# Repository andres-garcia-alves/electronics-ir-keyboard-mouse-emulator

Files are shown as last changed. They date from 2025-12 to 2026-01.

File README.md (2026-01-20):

# IR Keyboard+Mouse Emulator

Electronic project for use a IR Remote Control to control a Home Theater PC (HTPC) based on Arduino PRO Micro.  
Schematics diagram + PCB diagram (KiCAD 9) and case 3D model (Blender) are also provided.

This project comes in two versions: `Allways On` and `Low Power`.  
**Very important**: the current status of the `Low Power` version is **not working**, maybe I'll give it another try in the future.

- The `Allways On` version provides an immediate response when a remote control button is pressed.  
However, the gadget will constantly draw approximately 35-40mA from the USB port.

- The `Low Power` version automatically powers down the device after 30 seconds of inactivity, and it powers back on upon receiving an IR signal.  
This allows the gadget's power consumption to drop 99% of the time to ~1mA (the consumption of the IR sensor, the only component that remains powered on).  
However, due to the power-up time and the wait for the PC to recognize the device, there is a slight delay before it can be used.  
A high-side topology is used to power down the Arduino.
  - Hardware Variant A: External connection with a USB-A cable to J1 (USB-A socket).  
    Use a 2-strand cable from J2 (2-pins header) to the USB jack of Arduino for **data only** (D+/D-).
  - Hardware Variant B: External connection with a USB-B mini/micro cable to Arduino.  
    Cut the VCC wire of USB-B cable and pass it through J1 (2-pins header).

&nbsp;

General commands:
- Key Lock/Unlock (to avoid collition with regular TV usage).
- Key Esc
- Key Close (close current program)
- Mouse Change Speed
- Mouse Left Click
- Mouse Right Click
- Mouse MoveUp
- Mouse Move Right
- Mouse MoveDown
- Mouse MoveLeft

Media commands
- Media Player (open VLC media player)
- Media Play/Pause
- Media Stop
- Media Forward (moves forward 10 seconds)
- Media Rewind (moves backwards 10 seconds)
- Media Previous (moves forward 1 minute)
- Media Next (moves backwards 1 minute)
- Media Volume Mute
- Media Volume Up
- Media Volume Down

Miscellaneous commands
- MyPC (opens MyPC)
- Calculator (open Calculator);

Features:
- Dump of IR Codes (protocols: RC5, RC6, NEC, SONY, PANASONIC, LG, JVC, WHYNTER)

Benchmarks:

| Arduino PRO Micro | Tipical consumption |
|---|---|
| Normal mode | 37-38 mA |
| ADC + SPI + TWI disabled | 35-36 mA |
| USB detach + Clock @2 MHz | 19-20 mA |
| USB detach + SLEEP_MODE_PWR_DOWN  | 4-5 mA |

I am currently working on incorporating a hardware low-power version.

&nbsp;

The `Allways ON` version uses the following electronic components:
- 1 x Arduino PRO Micro
- 1 x IR Receiver VS1838
- 1 x LED 3mm
- 1 x 1k ohm resistor

The `Low Power` version uses the following electronic components:
- 1 x Arduino PRO Micro
- 1 x IR Receiver VS1838
- 1 x LED 3mm
- 1 x 1k ohm resistor
- 1 x 47k ohm resistor
- 2 x 10k ohm resistor
- 1 x 100k ohm resistor
- 2 x 4.7k ohm resistor
- 3 x 1N4148 schottky diode
- 1 x 10uF electrolitic capacitor
- 3 x BC547 PNP transistor
- 2 x BC557 NPN transistor
- 1 x USB Type-A female connector
- 1 x Bornier 2-pins / JST connector 2-pins

&nbsp;

### Version Allways On

| Breadboard | Assembly |
|---|---|
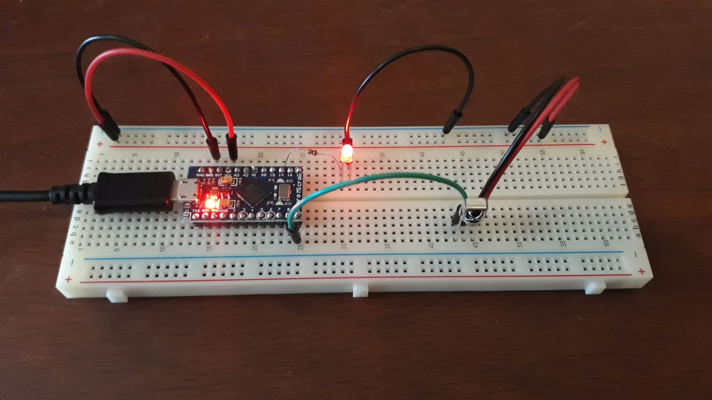
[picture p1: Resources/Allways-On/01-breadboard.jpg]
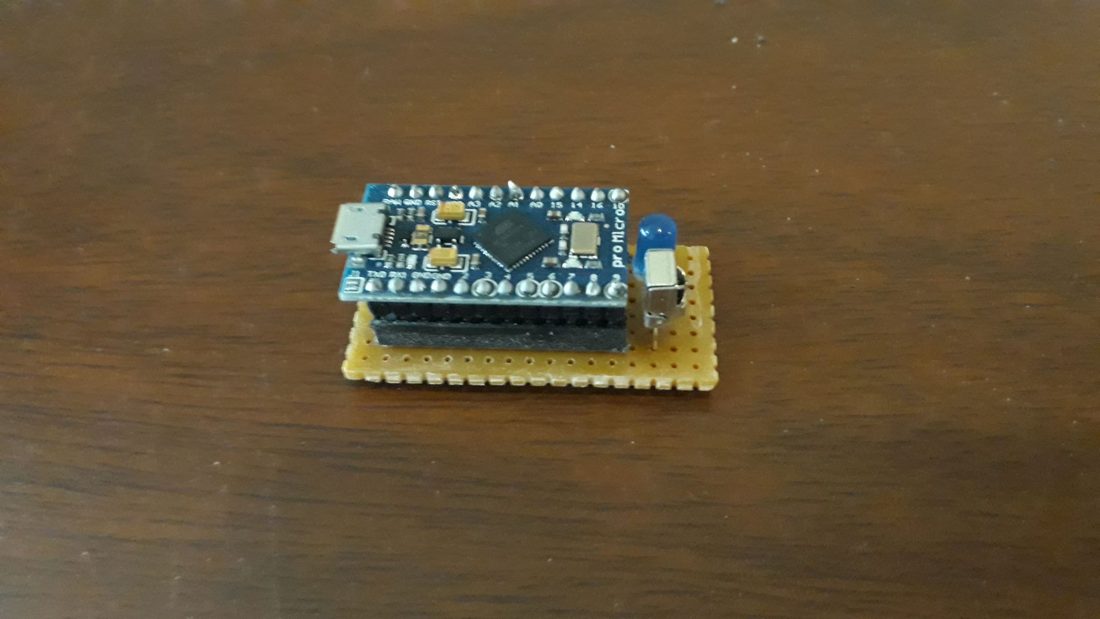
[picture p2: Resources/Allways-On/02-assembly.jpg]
|  |  |

| Schematics Diagram | PCB Diagram |
|---|---|
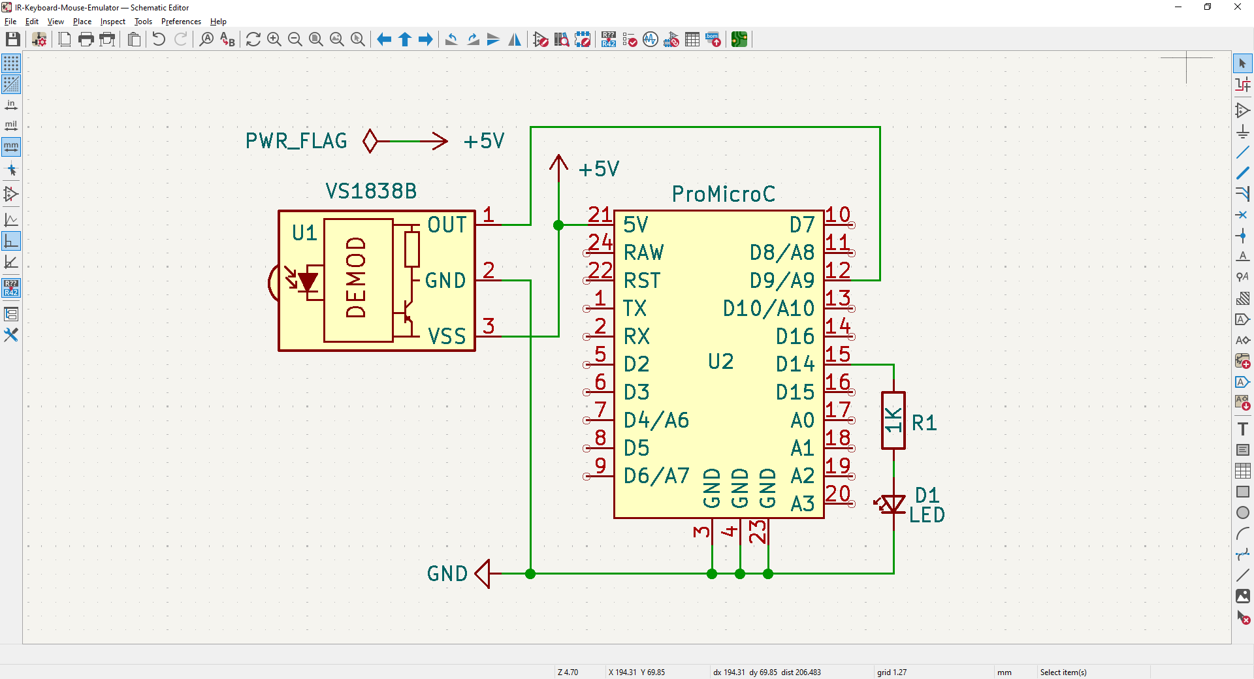
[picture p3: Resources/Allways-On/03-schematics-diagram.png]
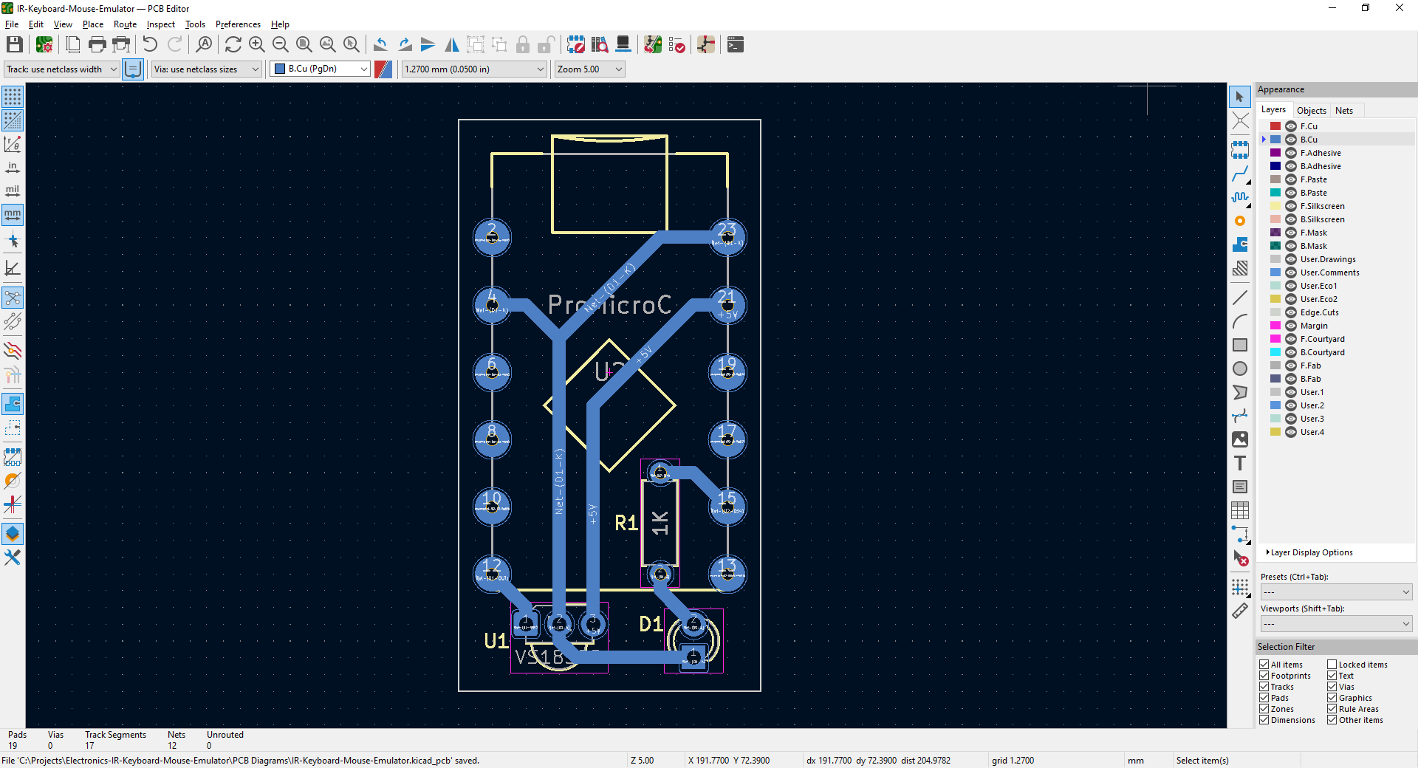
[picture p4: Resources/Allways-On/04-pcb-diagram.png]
|  |  |

| PCB Render 3D | PCB Render 3D |
|---|---|
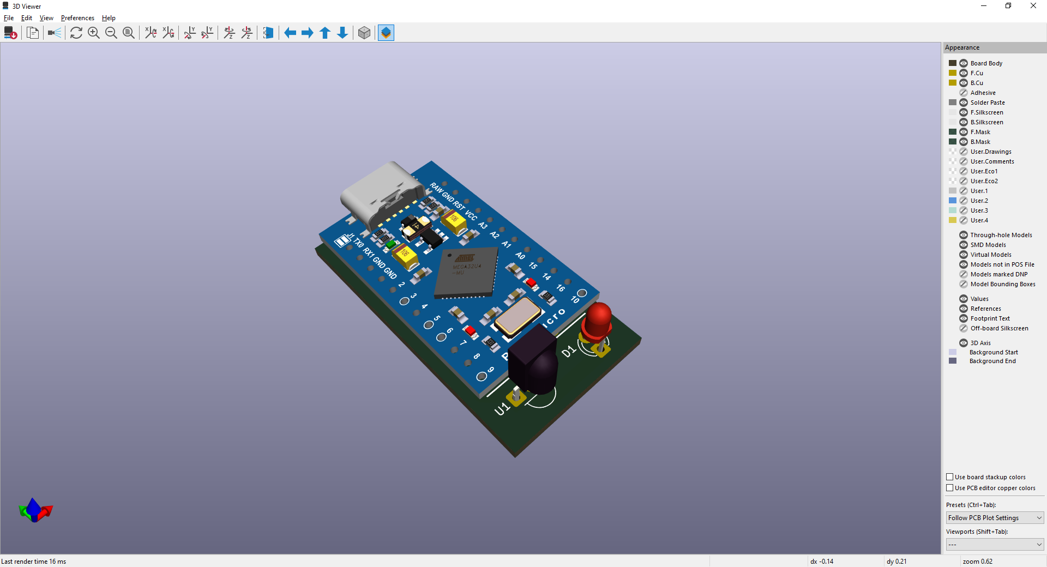
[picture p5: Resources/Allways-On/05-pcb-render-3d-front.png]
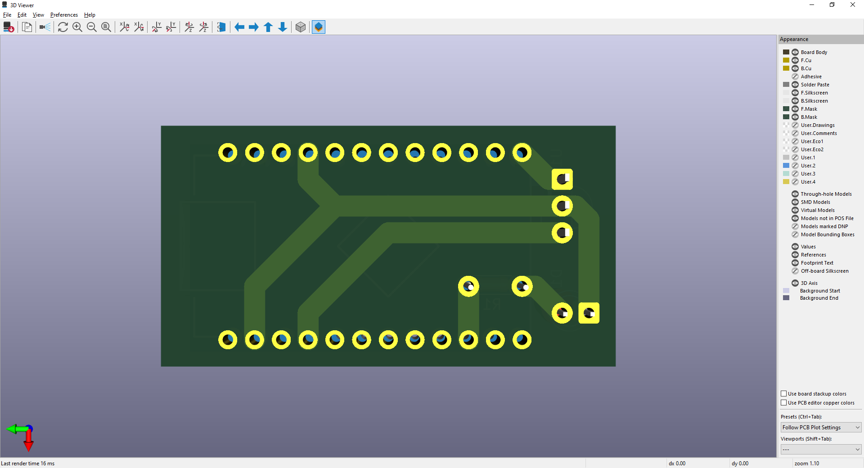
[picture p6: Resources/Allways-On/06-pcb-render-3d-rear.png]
|   |  |

| Case 3D Model | Project Final |
|---|---|
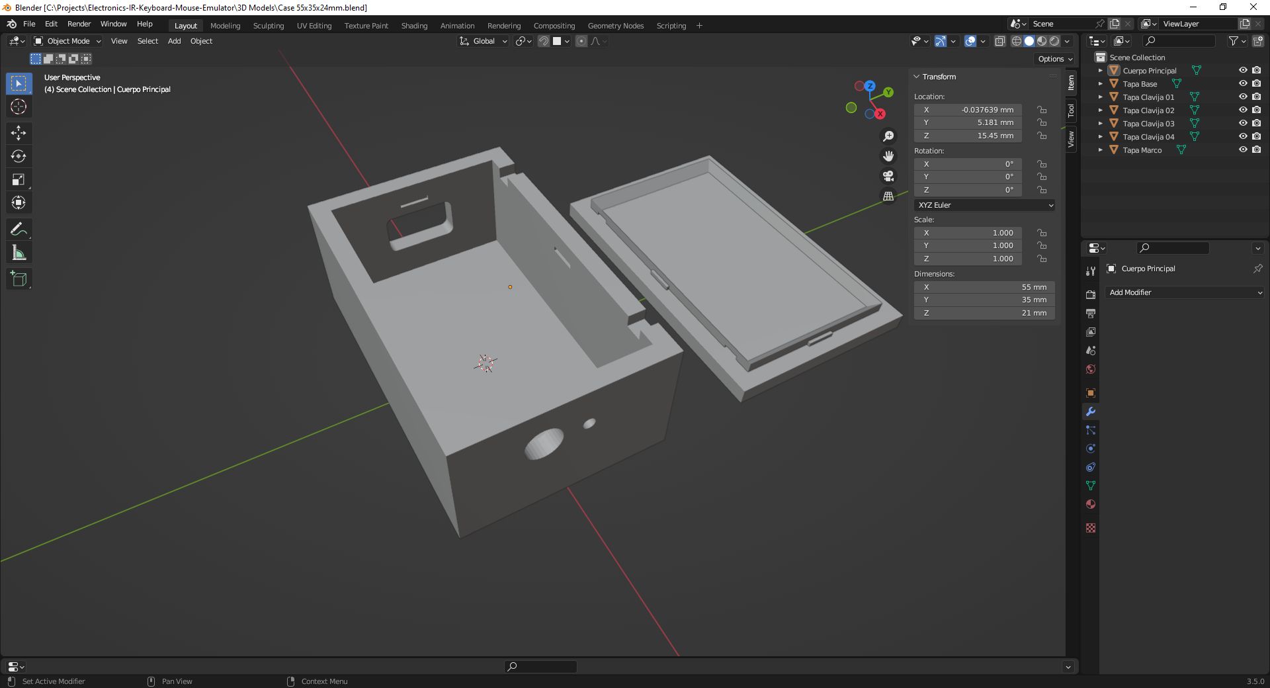
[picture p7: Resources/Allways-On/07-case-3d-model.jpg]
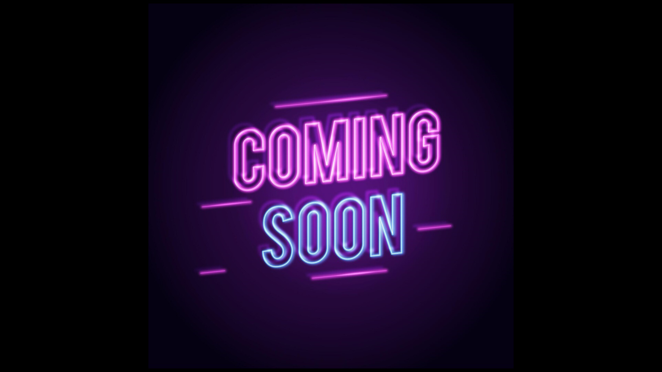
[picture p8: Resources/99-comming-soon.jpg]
|  |  |

&nbsp;

### Version Low-Power-B

| Breadboard | Assembly |
|---|---|
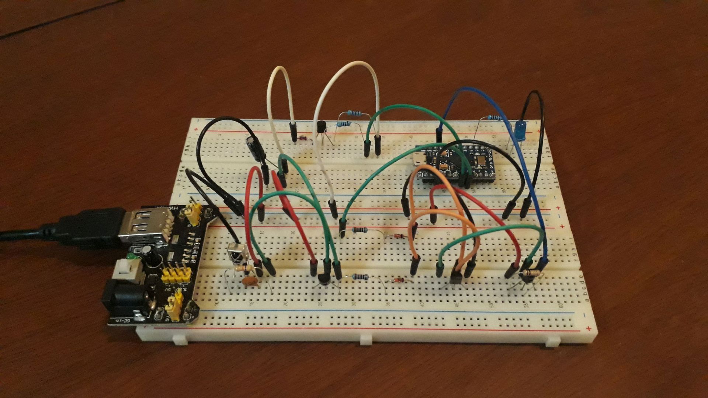
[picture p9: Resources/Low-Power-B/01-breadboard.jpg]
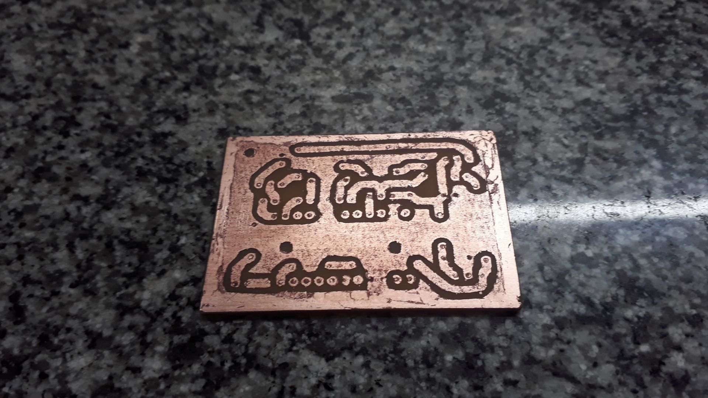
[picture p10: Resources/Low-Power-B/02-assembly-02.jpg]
|  |  |

| Assembly | Assembly |
|---|---|
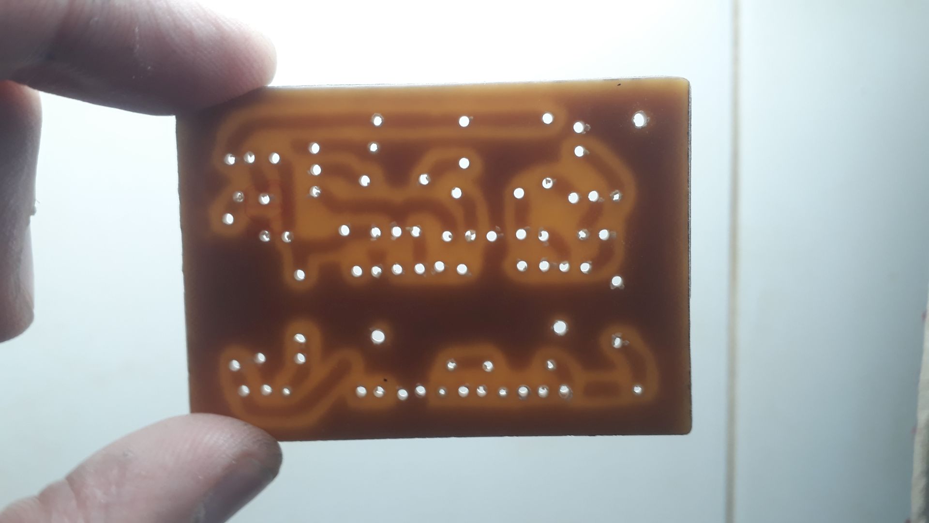
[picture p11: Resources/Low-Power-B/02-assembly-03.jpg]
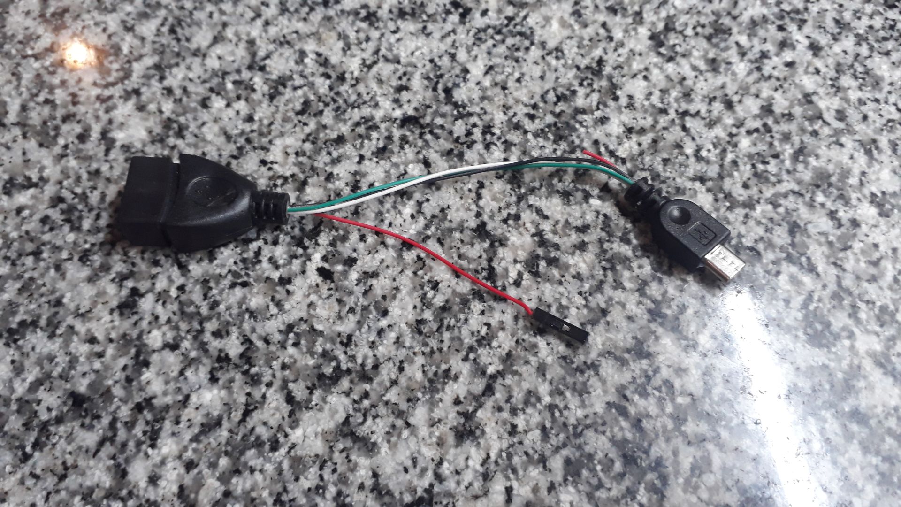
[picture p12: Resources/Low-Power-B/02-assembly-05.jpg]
|  |  |

| Schematics Diagram | PCB Diagram |
|---|---|
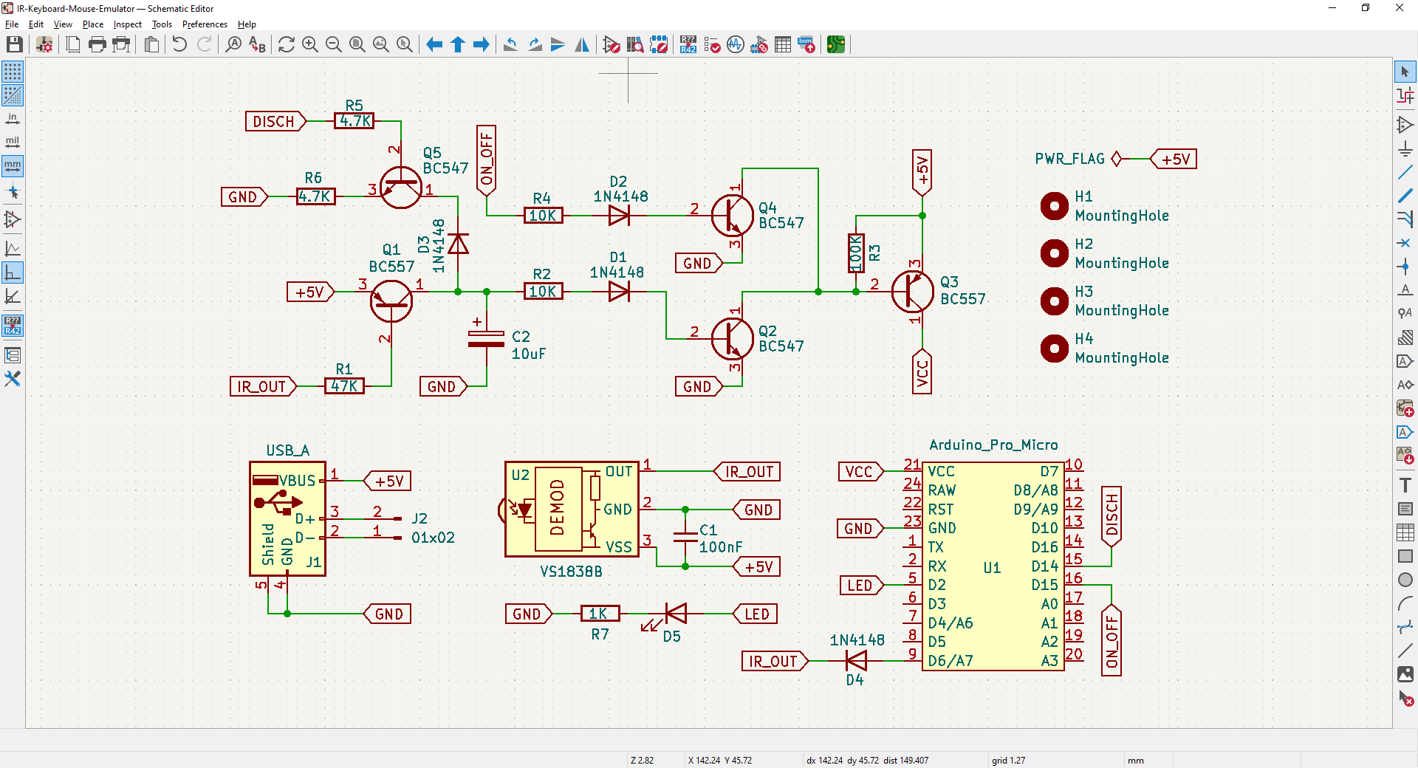
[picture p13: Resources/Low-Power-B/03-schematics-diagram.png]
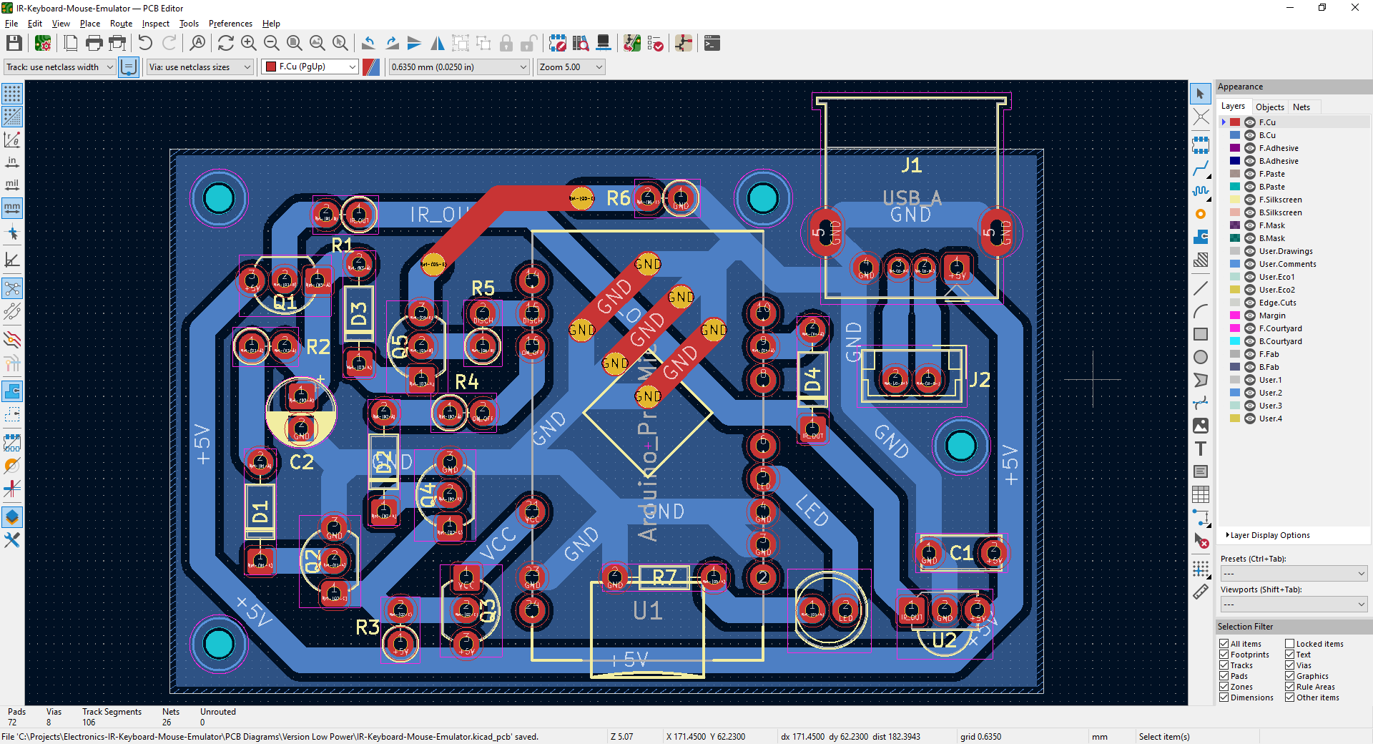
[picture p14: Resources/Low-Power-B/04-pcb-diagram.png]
|   |  |

| PCB Render 3D | PCB Render 3D |
|---|---|
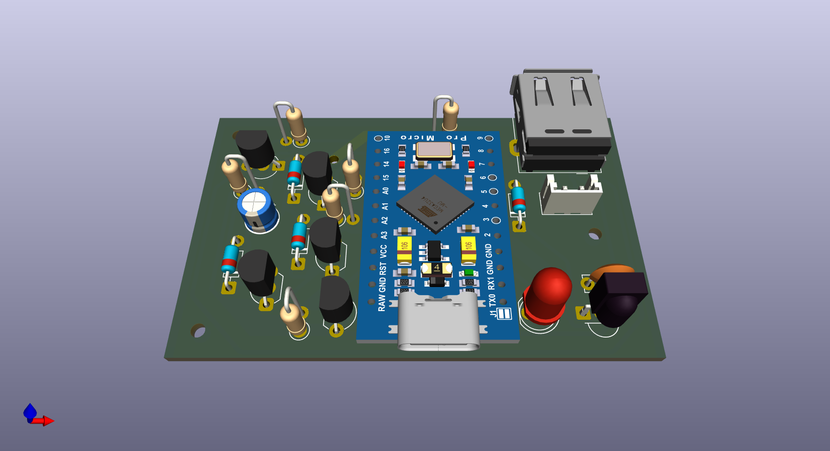
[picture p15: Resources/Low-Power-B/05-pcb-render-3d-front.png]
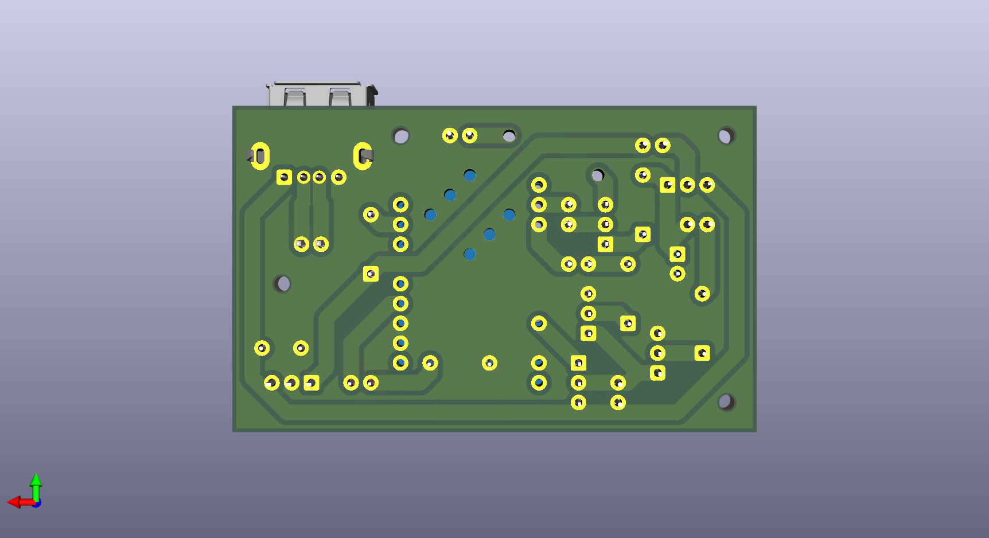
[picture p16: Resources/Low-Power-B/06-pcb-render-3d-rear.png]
|  |   |

| Case 3D Model | Project Final |
|---|---|
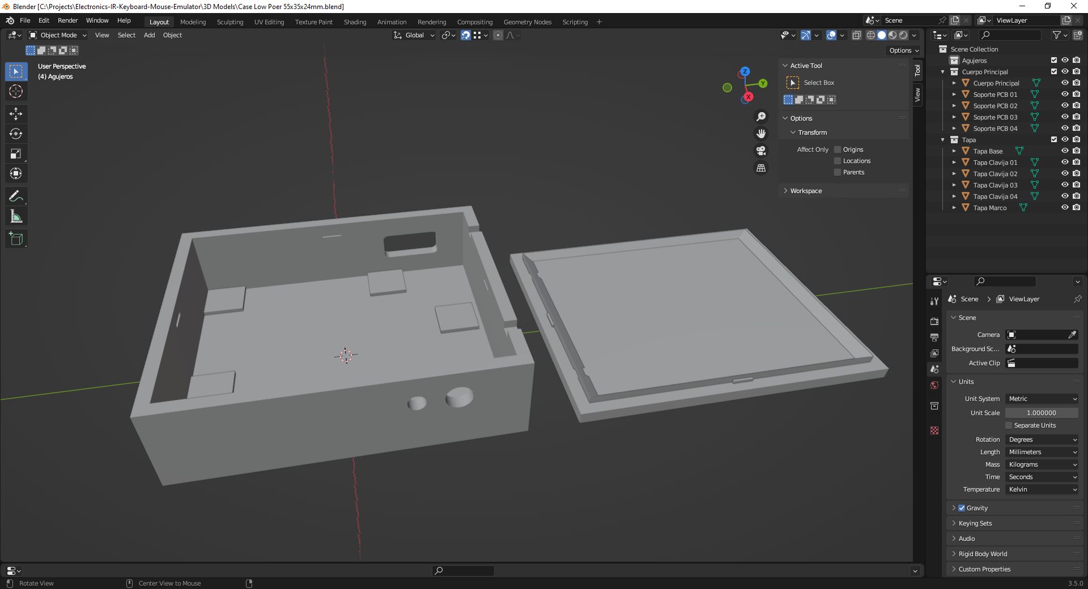
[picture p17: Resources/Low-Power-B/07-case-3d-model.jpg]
|  |  |

See 'Rescources' sub-folder for more pictures & videos of the project.

&nbsp;

### Version History

v1.00 (2025.12.18) - Initial release.  
v1.01 (2025.12.19) - Adding case 3D model.  
v1.02 (2025.12.22) - Update schematics and PCB.  
v1.03 (2025.12.29) - Firmware refactor for code clean-up.  
v1.04 (2026.01.02) - Adding Low-Power-A version protoboard & schematics.  
v1.05 (2026.01.03) - Adding Low-Power-A version firmware.  
v1.06 (2026.01.04) - Adding Low-Power-A version PCB.  
v1.07 (2026.01.04) - Adding Low-Power-A case 3D model.  
v1.08 (2026.01.06) - Minor fixes on Low-Power-A case 3D model.  
v1.09 (2026.01.09) - Minor fixes on Low-Power-A PCB.  
v1.10 (2026.01.14) - Adding Low-Power-B version schematics & PCB.  
v1.11 (2026.01.15) - Adding Low-Power-B 3D model.  
v1.12 (2026.01.18) - Minor fixes on Low-Power-B 3D model.  

&nbsp;

This source code is licensed under GPL v3.0  
Please send me your feedback about this project: andres.garcia.alves@gmail.com

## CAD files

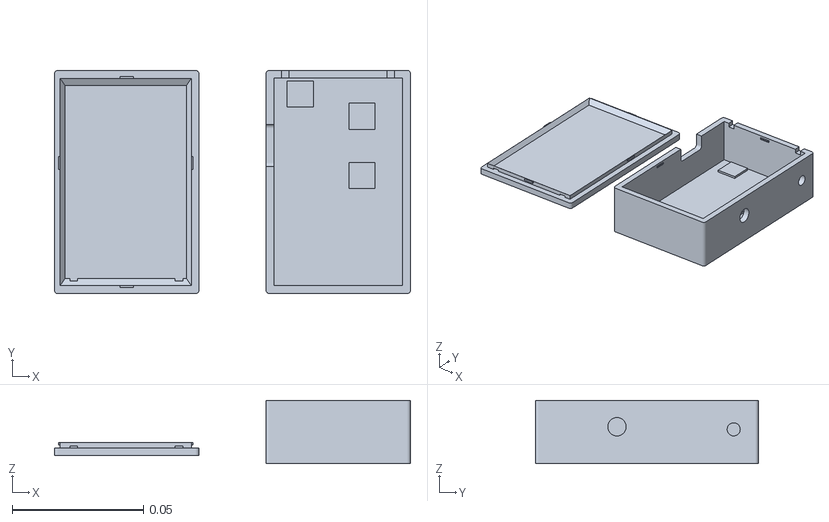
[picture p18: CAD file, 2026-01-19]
3D Models/Case Low-Power-B 85x55x27mm (final).stl
0.136 x 0.085 x 0.024

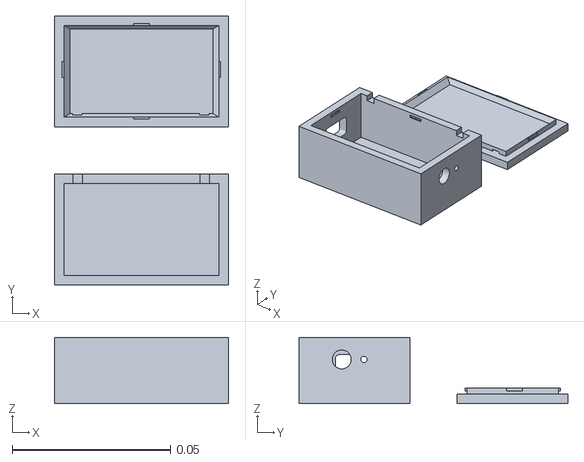
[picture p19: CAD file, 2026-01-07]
3D Models/Case Allways-On 55x35x24mm (final).stl
0.055 x 0.085 x 0.021

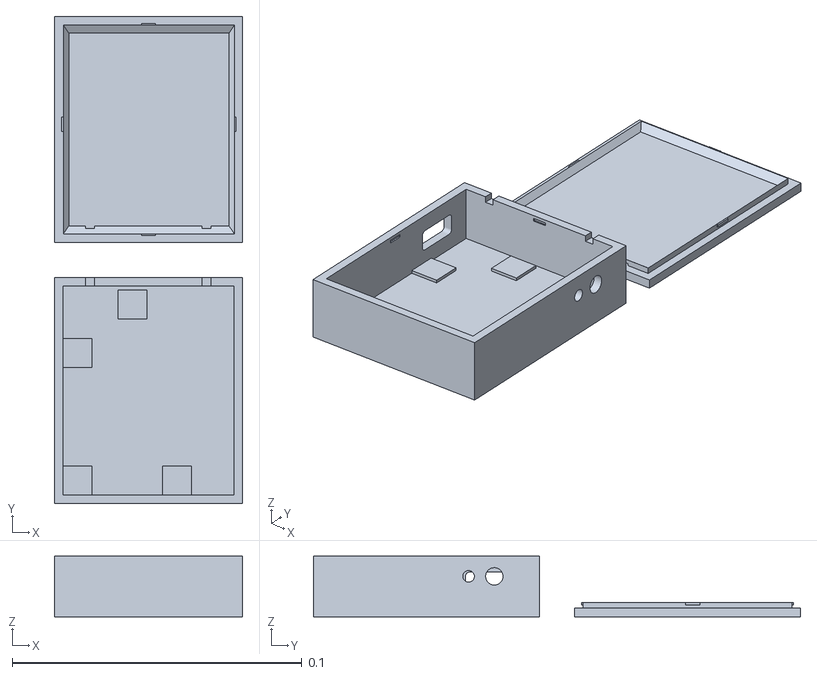
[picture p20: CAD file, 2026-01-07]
3D Models/Case Low-Power-A 65x78x24mm (final).stl
0.065 x 0.168 x 0.021

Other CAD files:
3D Models/Case Allways-On 55x35x24mm (final).blend
3D Models/Case Allways-On 55x35x24mm (without holes).blend
3D Models/Case Low-Power-A 65x78x24mm (final).blend
3D Models/Case Low-Power-A 65x78x24mm (without holes).blend
3D Models/Case Low-Power-B 85x55x27mm (final).blend
3D Models/Case Low-Power-B 85x55x27mm (without holes).blend

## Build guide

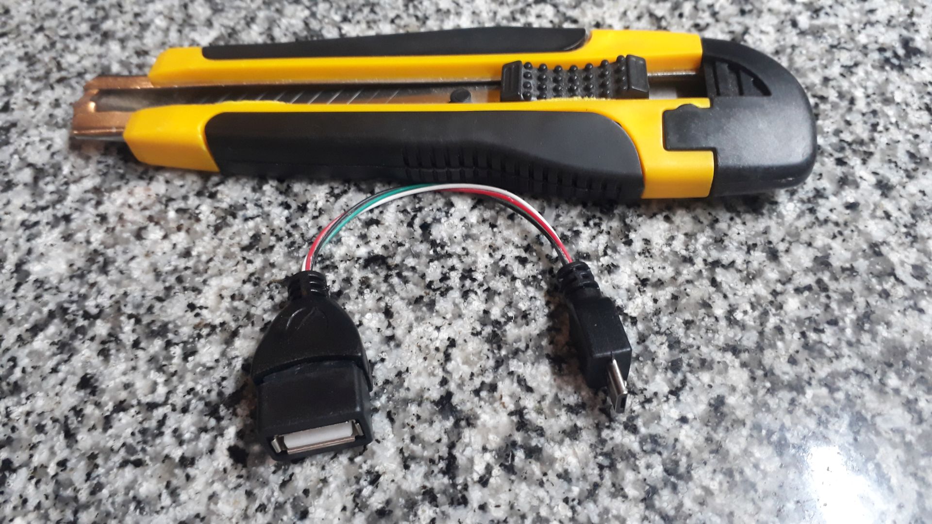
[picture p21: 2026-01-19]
Resources/Low-Power-B/02-assembly-04.jpg

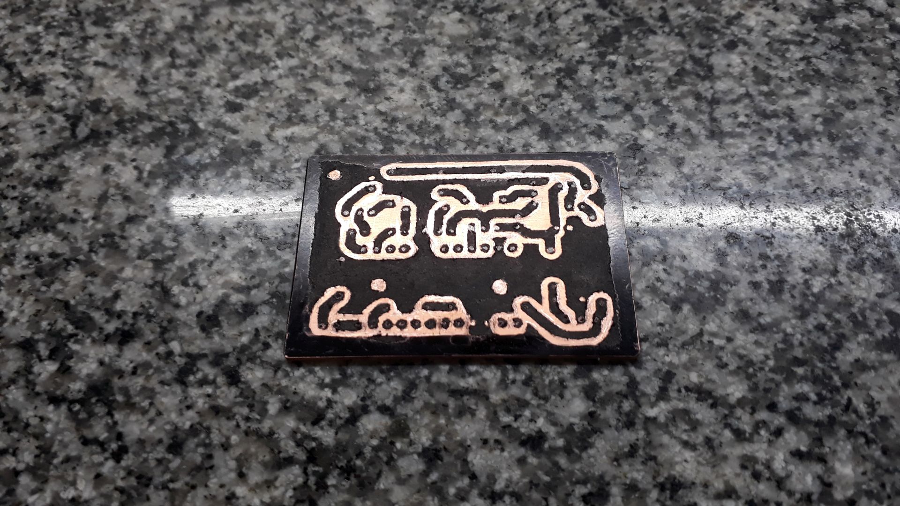
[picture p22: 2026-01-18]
Resources/Low-Power-B/02-assembly-01.jpg

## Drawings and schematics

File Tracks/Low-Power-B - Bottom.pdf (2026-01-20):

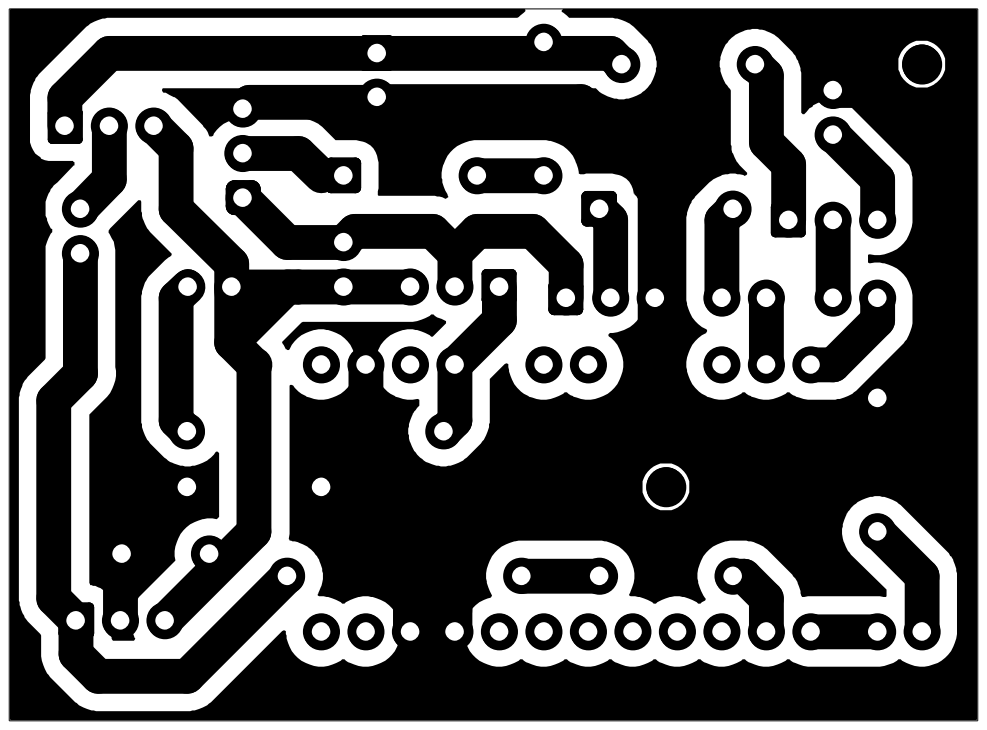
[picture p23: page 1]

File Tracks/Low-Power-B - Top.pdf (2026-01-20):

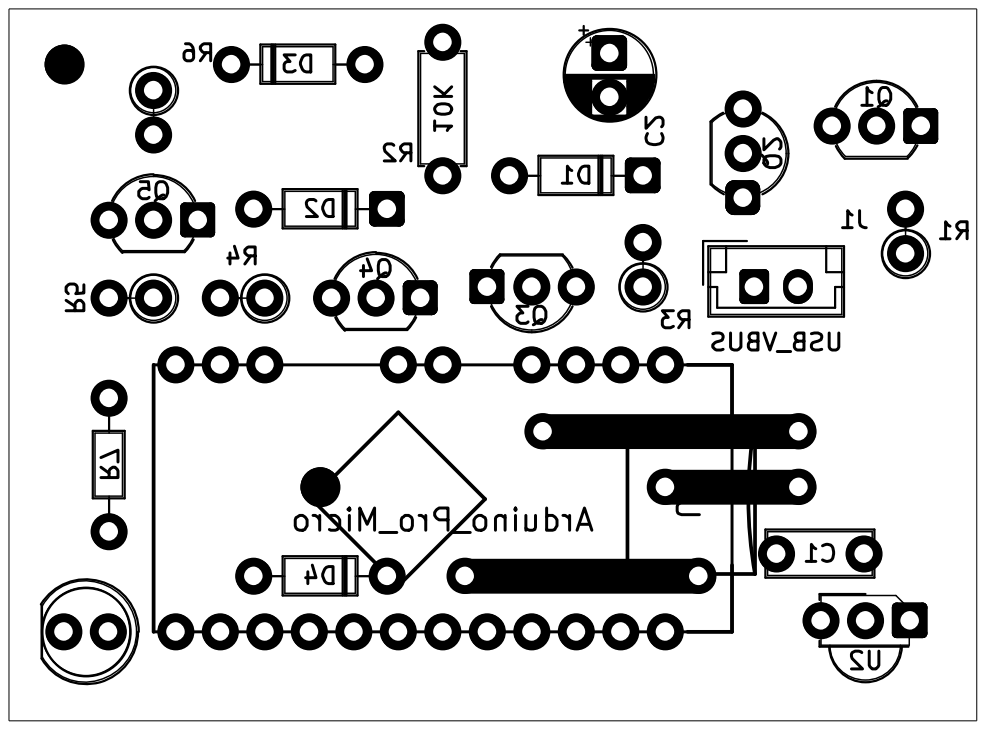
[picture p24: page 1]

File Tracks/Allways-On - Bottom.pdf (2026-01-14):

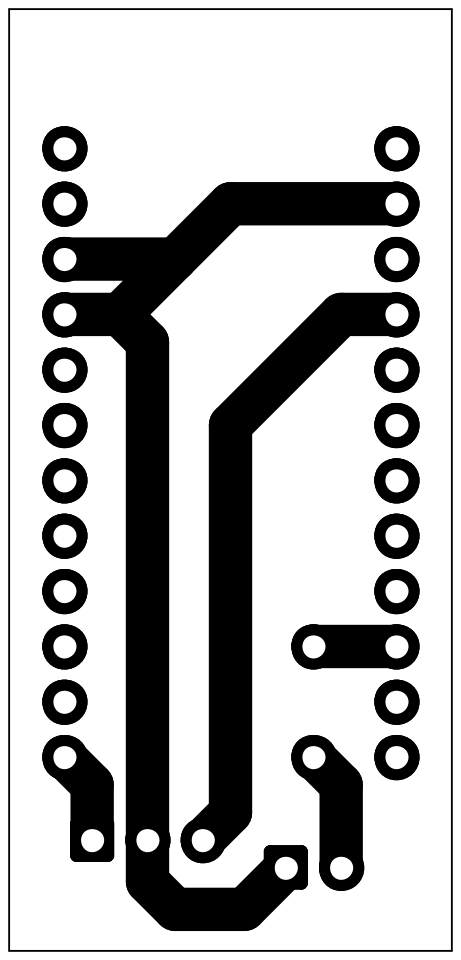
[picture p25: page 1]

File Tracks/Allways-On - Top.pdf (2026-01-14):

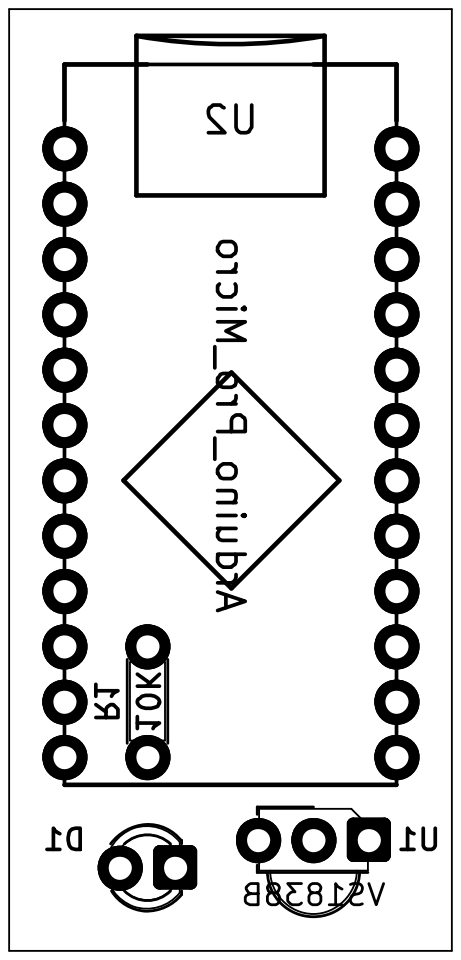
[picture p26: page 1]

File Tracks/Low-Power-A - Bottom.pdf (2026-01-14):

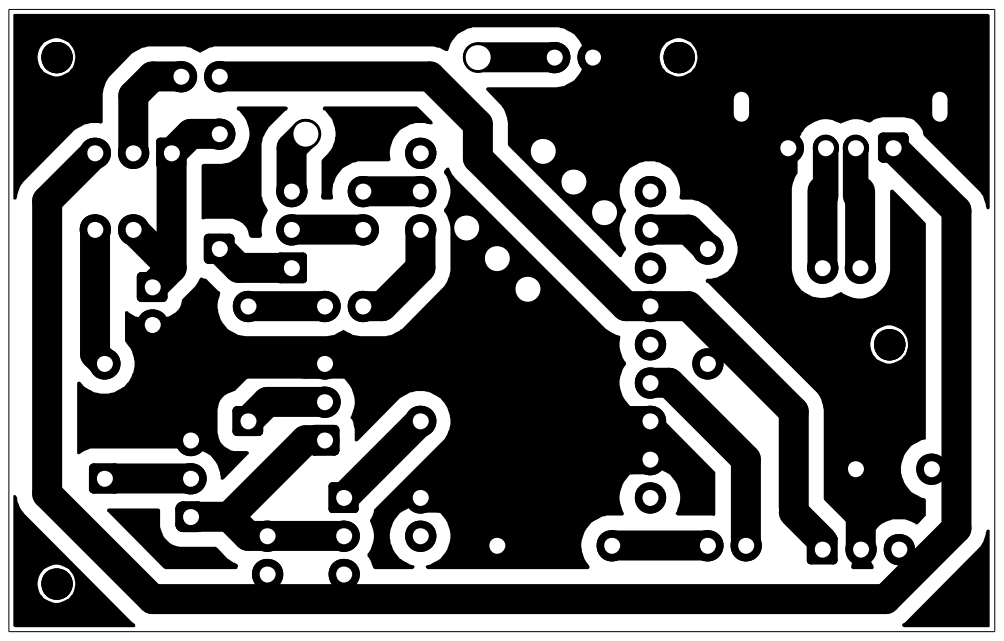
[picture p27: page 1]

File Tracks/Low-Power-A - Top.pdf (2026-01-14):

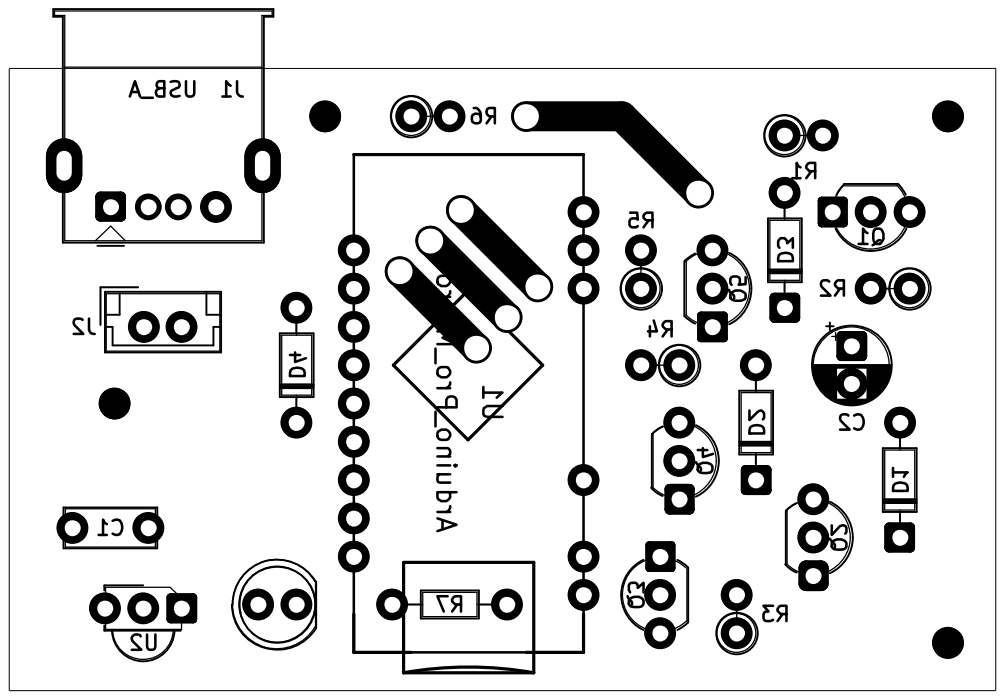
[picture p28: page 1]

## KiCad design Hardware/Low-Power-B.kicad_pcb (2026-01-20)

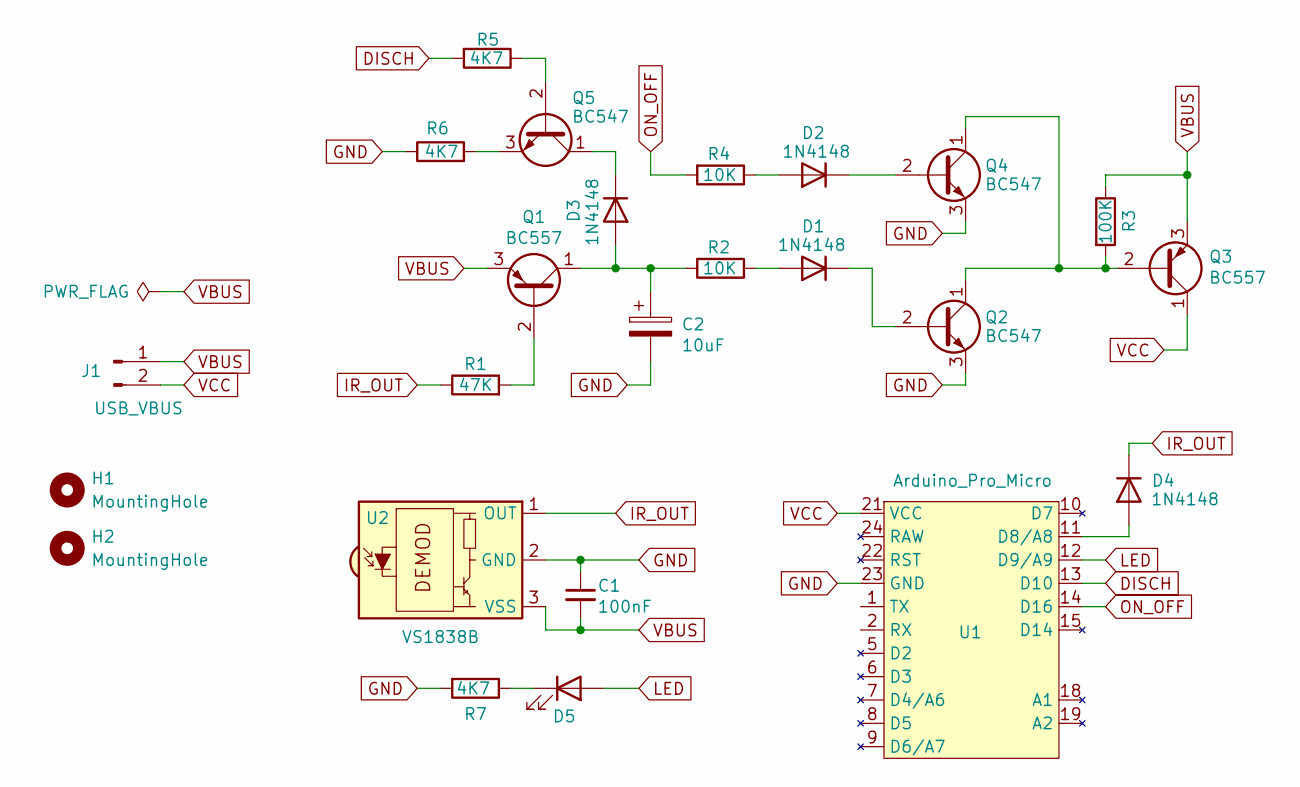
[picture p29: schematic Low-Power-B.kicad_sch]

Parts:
C1: 100nF; C_Disc_D6.0mm_W2.5mm_P5.00mm; Voltage 1kV; Tolerance 100%
C2: 10uF; CP_Radial_D5.0mm_P2.50mm
D1, D2, D3, D4: 1N4148; D_DO-35_SOD27_P7.62mm_Horizontal
D5: LED; LED_D5.0mm
H1, H2: MountingHole; MountingHole_2.2mm_M2_ISO7380
J1: USB_VBUS; JST_EH_B2B-EH-A_1x02_P2.50mm_Vertical
Q1, Q3: BC557; TO-92_Inline_Wide
Q2, Q4, Q5: BC547; TO-92_Inline_Wide
R1: 47K; R_Axial_DIN0207_L6.3mm_D2.5mm_P2.54mm_Vertical
R2: 10K; R_Axial_DIN0207_L6.3mm_D2.5mm_P7.62mm_Horizontal
R3: 100K; R_Axial_DIN0207_L6.3mm_D2.5mm_P2.54mm_Vertical
R4: 10K; R_Axial_DIN0207_L6.3mm_D2.5mm_P2.54mm_Vertical
R5, R6: 4K7; R_Axial_DIN0207_L6.3mm_D2.5mm_P2.54mm_Vertical
R7: 4K7; R_Axial_DIN0204_L3.6mm_D1.6mm_P7.62mm_Horizontal
U1: Arduino_Pro_Micro
U2: VS1838B; Vishay_MINICAST-3Pin

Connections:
DISCH: R5.2, U1.13 (D10)
GND: C1.1, C2.2, Q2.3 (E), Q4.3 (E), R6.1, R7.2, U1.3 (GND), U1.4 (GND), U1.23 (GND), U2.2 (GND)
IR_OUT: D4.1 (K), R1.1, U2.1 (OUT)
LED: D5.2 (A), U1.12 (D9/A9)
unnamed: D1.2 (A), R2.1
unnamed: D1.1 (K), Q2.2 (B)
unnamed: D2.2 (A), R4.1
unnamed: D2.1 (K), Q4.2 (B)
unnamed: C2.1, D3.2 (A), Q1.1 (C), R2.2
unnamed: D3.1 (K), Q5.1 (C)
unnamed: D4.2 (A), U1.11 (D8/A8)
unnamed: D5.1 (K), R7.1
unnamed: Q1.2 (B), R1.2
unnamed: Q2.1 (C), Q3.2 (B), Q4.1 (C), R3.2
unnamed: Q5.2 (B), R5.1
unnamed: Q5.3 (E), R6.2
ON_OFF: R4.2, U1.14 (D16)
VBUS: C1.2, J1.1, Q1.3 (E), Q3.3 (E), R3.1, U2.3 (VSS)
VCC: J1.2, Q3.1 (C), U1.21 (VCC)

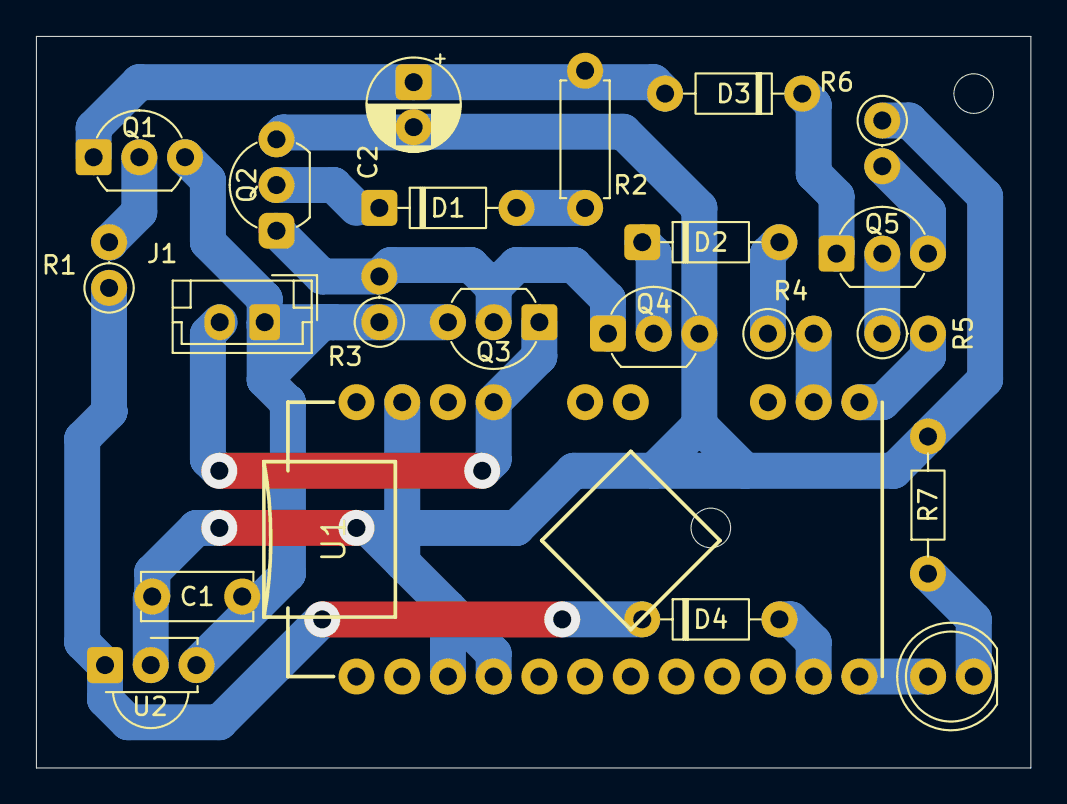
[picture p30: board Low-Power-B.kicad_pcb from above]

Board: 2 copper layers, 55.2 x 40.6 mm, 24 parts (0 on the bottom side), 19 nets.

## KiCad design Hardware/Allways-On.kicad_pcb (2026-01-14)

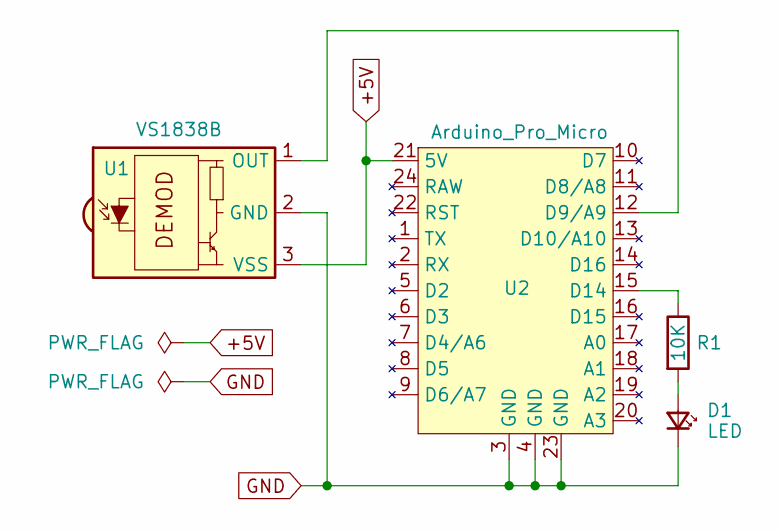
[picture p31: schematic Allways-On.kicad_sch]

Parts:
D1: LED; LED_D3.0mm
R1: 10K; R_Axial_DIN0204_L3.6mm_D1.6mm_P5.08mm_Horizontal
U1: VS1838B; Vishay_MINICAST-3Pin
U2: Arduino_Pro_Micro

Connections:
+5V: U1.3 (VSS), U2.21 (5V)
GND: D1.1 (K), U1.2 (GND), U2.3 (GND), U2.4 (GND), U2.23 (GND)
unnamed: D1.2 (A), R1.2
unnamed: U1.1 (OUT), U2.12 (D9/A9)
unnamed: R1.1, U2.15 (D14)

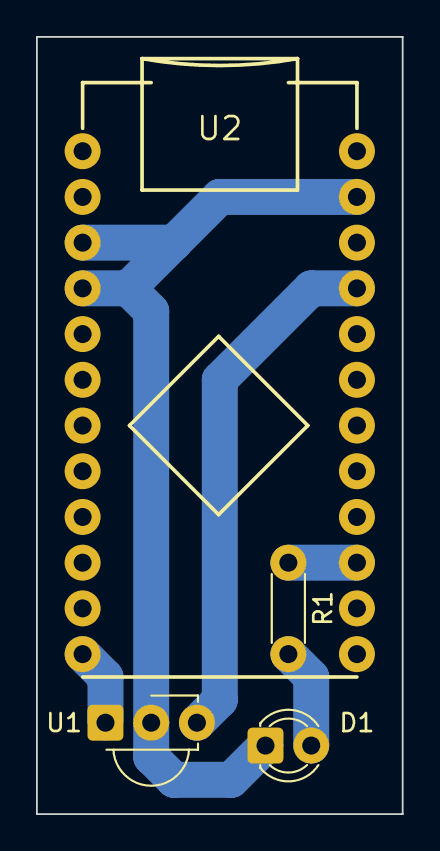
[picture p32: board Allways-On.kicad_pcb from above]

Board: 2 copper layers, 20.3 x 43.2 mm, 4 parts (0 on the bottom side), 5 nets.

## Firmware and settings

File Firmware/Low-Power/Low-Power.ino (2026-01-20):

#include <Arduino.h>
#include <IRremote.hpp>
#include "hardware.h"
#include "debug.h"
#include "locking.h"
#include "commands.h"
#include "input.h"
#include "power_hw.h"

void setup() {

  delay(100);               // safety measure
  hardwareInit();           // hardware pin modes

  debugInit();              // debuging
  irRemoteInit(IrReceiver); // full reset of IRremote
  commandsInit();           // HID: media keys, keyboard & mouse
  powerInit();              // disable unnecessary hardware

  delay(100);
  debugMessage("System ready");
  delay(100);
}

void loop() {

  if (IrReceiver.decode()) {

    markActivity();
    debugIrReceiverData(IrReceiver.decodedIRData.protocol, IrReceiver.decodedIRData.decodedRawData);

    // NEC protocol uses codes in format 0x1036/0x1836 alternatively, ignore bit 0x0800
    uint16_t code = NEC_NORMALIZE(IrReceiver.decodedIRData.decodedRawData);

    // wake-up all arduino features
    // handleLowPowerMode();

    // process pressed key
    handleInput(isLocked(), code);

    IrReceiver.resume();
  }

  handlePower();
  // handleAutoSleep();
}

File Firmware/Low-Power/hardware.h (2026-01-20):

#ifndef HARDWARE_H
#define HARDWARE_H

/* DEFINITIONS */
#define DELAY_IR_RECEIVER     100


/* LOW POWER VERSION SELECTION */
#define LOW_POWER_VERSION       'B'   // 'A' or 'B' (see README.md)


/* HARDWARE DEFINITIONS */
#if LOW_POWER_VERSION == 'A'          // LOW-POWER-A
  #define PIN_IR_RECEIVER       6     // IR Reciever (VS1838) pin
  #define PIN_LED               2     // LED pin
  #define PIN_LATCH_ON_OFF      15    // Arduino Power Latch pin
  #define PIN_LATCH_CAP_DISCH   14    // Capacitor (C1) Power Latch pin
#elif LOW_POWER_VERSION == 'B'        // LOW-POWER-B
  #define PIN_IR_RECEIVER       8     // IR Reciever (VS1838) pin
  #define PIN_LED               9     // LED pin
  #define PIN_LATCH_ON_OFF      16    // Arduino Power Latch pin
  #define PIN_LATCH_CAP_DISCH   10    // Capacitor (C1) Power Latch pin
#else
  #error "Invalid LOW_POWER_VERSION: use 'A' or 'B'"
#endif


void hardwareInit() {

  // setup arduino power latch
  pinMode(PIN_LATCH_ON_OFF, OUTPUT);
  digitalWrite(PIN_LATCH_ON_OFF, HIGH);

  // hold C1 power latch for a while
  pinMode(PIN_LATCH_CAP_DISCH, OUTPUT);
  digitalWrite(PIN_LATCH_CAP_DISCH, LOW);

  // IR receiver
  pinMode(PIN_IR_RECEIVER, INPUT);

  // feedback LED
  pinMode(PIN_LED, OUTPUT);
  digitalWrite(PIN_LED, HIGH);
}

void irRemoteInit(IRrecv &receiver) {

  receiver.stop();
  delay(DELAY_IR_RECEIVER);
  receiver.end();
  delay(DELAY_IR_RECEIVER);
  receiver.begin(PIN_IR_RECEIVER, ENABLE_LED_FEEDBACK);
  delay(DELAY_IR_RECEIVER);
}

#endif

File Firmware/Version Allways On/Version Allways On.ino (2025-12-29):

#include <Arduino.h>
#include <IRremote.hpp>
#include "definitions.h"
#include "debug.h"
#include "locking.h"
#include "commands.h"
#include "input.h"
#include "power.h"

void handleInput(uint16_t);

void setup() {

  delay(DELAY_START);

  debugInit();
  irRemoteInit();   // full stop init cicle of IRremote
  commandsInit();   // HID: media keys, keyboard & mouse
  inputInit();      // pin modes for receiver & feedback led
  powerInit();      // disable unnecessary hardware
  
  debugMessage("System ready");
}

void loop() {

  if (IrReceiver.decode()) {

    debugIrReceiverData(IrReceiver.decodedIRData.protocol, IrReceiver.decodedIRData.decodedRawData);

    // NEC protocol uses codes in format 0x1036/0x1836 alternatively, ignore bit 0x0800
    uint16_t code = NEC_NORMALIZE(IrReceiver.decodedIRData.decodedRawData);

    // wake-up all arduino features
    /*if (isLowPowerMode()) {
      setNormalPowerMode();
      irRemoteInit();
    }*/

    // process pressed key
    handleInput(isLocked(), code);
    markActivity();

    IrReceiver.resume();
  }

  // handleAutoSleep();
  delay(DELAY_LOOP);
}


void irRemoteInit() {

  IrReceiver.stop();
  delay(DELAY_STANDARD);
  IrReceiver.end();
  delay(DELAY_STANDARD);
  IrReceiver.begin(PIN_RECEIVER, ENABLE_LED_FEEDBACK);
  delay(DELAY_STANDARD);
}

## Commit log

2025-12-19 adding 3D Model
    [Case 55x35x23mm (without holes).blend, Case 55x35x23mm.blend, Case 55x35x23mm.stl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]
2025-12-19 adding case 3D model
    [Case 55x35x23mm (without holes).blend, Case 55x35x23mm.blend, Case 55x35x23mm.stl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]
2025-12-20 update project structure
    [IR-Keyboard-Mouse-Emulator.kicad_pcb, IR-Keyboard-Mouse-Emulator.kicad_sch]
2025-12-22 update schematics and pcb
    [IR-Keyboard-Mouse-Emulator.kicad_pcb, IR-Keyboard-Mouse-Emulator.kicad_sch]
2026-01-03 Adding Low Power protoboard & schematics diagram
    [Case 55x35x24mm.blend, IR-Keyboard-Mouse-Emulator.kicad_pcb, IR-Keyboard-Mouse-Emulator.kicad_sch]
2026-01-03 Adding low-power firmware
    [IR-Keyboard-Mouse-Emulator.kicad_pcb, IR-Keyboard-Mouse-Emulator.kicad_sch]
2026-01-04 Adding low-power version PCB
    [IR-Keyboard-Mouse-Emulator.kicad_pcb, IR-Keyboard-Mouse-Emulator.kicad_sch]
2026-01-04 Adding low-power case 3D model
    [Case Low Power 65x78x24mm (without holes).blend, Case Low Power 65x78x24mm.blend, Case Low Power 65x78x24mm.stl]
2026-01-07 Minor fixes on low-power case 3D model
    [Case Allways On 55x35x24mm (final).blend, Case Allways On 55x35x24mm (final).stl, Case Allways On 55x35x24mm (without holes).blend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]
2026-01-09 Minor fixes on low-power PCB
    [Allways-On.kicad_pcb, Allways-On.kicad_sch, Low-Power.kicad_pcb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]
2026-01-13 Adding 'Resources' for Low-Power version
    [Low-Power.kicad_pcb]
2026-01-14 Minor fixes on allways-on PCB
    [Allways-On.kicad_pcb, Allways-On.kicad_sch, Low-Power.kicad_pcb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]
2026-01-14 Adding Low-Power-B version schematics & PCB
    [Low-Power-A.kicad_pcb, Low-Power-A.kicad_sch, Low-Power-B.kicad_pcb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]
2026-01-15 Adding Low-Power-B 3D model
    [Case Allways-On 55x35x24mm (final).blend, Case Allways-On 55x35x24mm (final).stl, Case Allways-On 55x35x24mm (without holes).blend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]
2026-01-18 Minor fixes on Low-Power-B 3D model
    [Case Low-Power-B 90x51x24mm (final).blend, Case Low-Power-B 90x51x24mm (final).stl, Case Low-Power-B 90x51x24mm (without holes).blend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]
